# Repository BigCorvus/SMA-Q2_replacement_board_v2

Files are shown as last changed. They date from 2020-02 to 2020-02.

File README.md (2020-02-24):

# SMA-Q2_replacement_board_v2
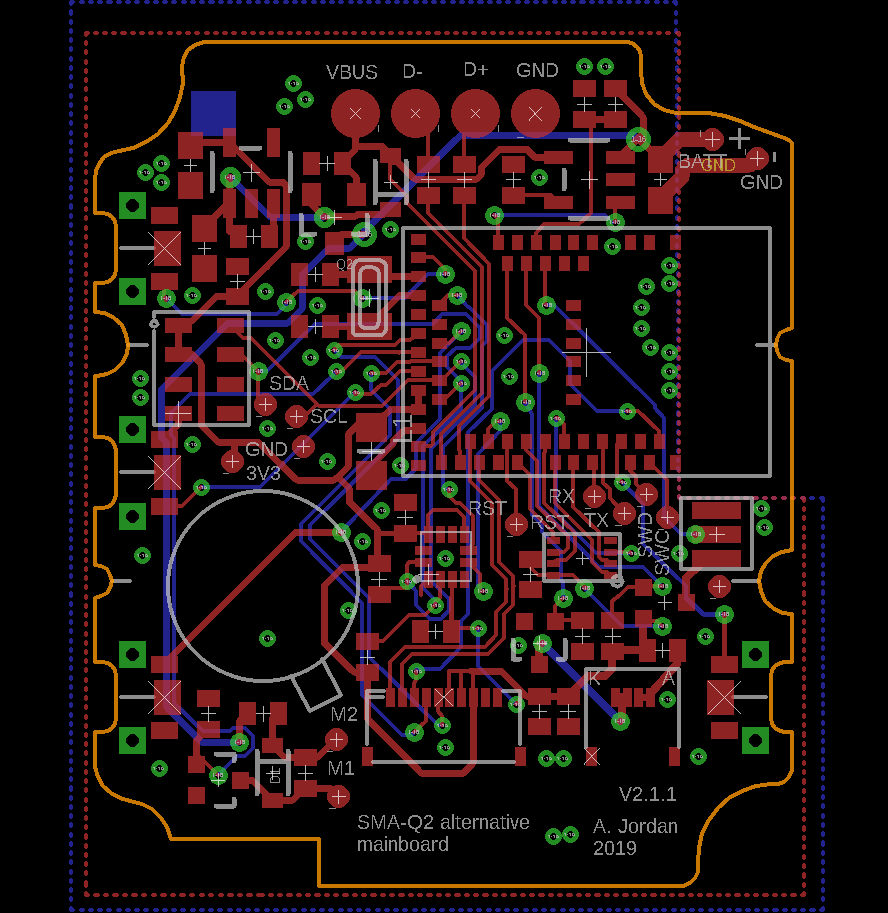
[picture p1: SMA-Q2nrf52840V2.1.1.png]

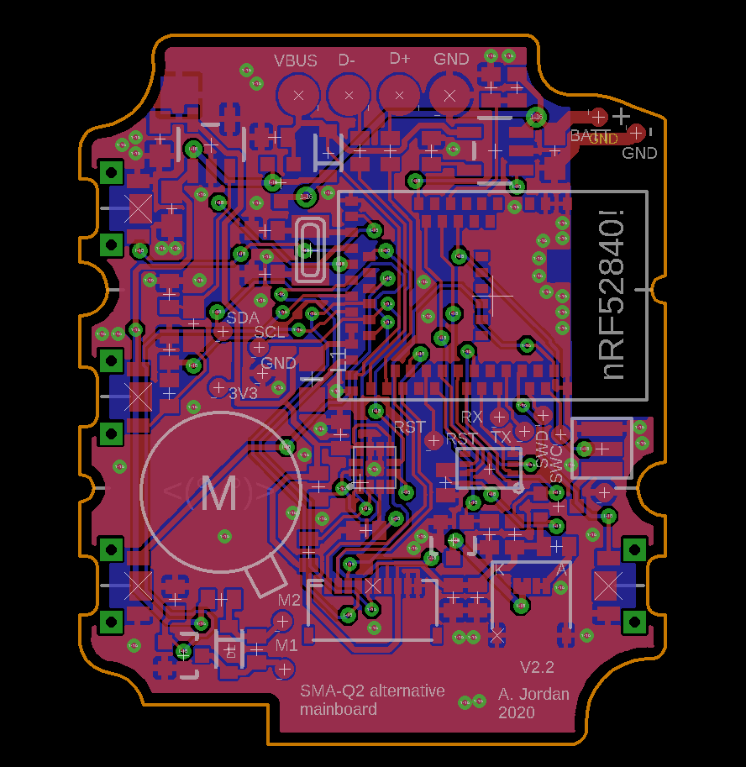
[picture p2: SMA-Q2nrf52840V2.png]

nRF5840-based replacement board for the SMA-Q2 smartwatch. Uses the MDBT50Q-1MV2 (and similar) module. Based on the Adafruit Feather nRF52840. Has to be fabricated on 0,8mm FR4 material. Main changes are: no external RTC, all mosfets in SOT-323 package (at least in v2.2), optional barometer and power latching circuit, everything controlled by the nRF52840.

2 versions have been created: v2.2 without MS5611 barometer, but with a simple power latching circuit. v2.1.1 does not have a power latching circuit, but has a footprint for a MS5611 barometer. Both versions use both interrupts of the accelerometer.  
During testing and everyday use RF performance turned out to be poor. The reason is the ceramic antenna which is shielded by the close proximity of the lipo battery. This problem was quite easy to solve in retrospective. I just desoldered the chip antenna with 2 soldering irons and connected a simple 30AWG wire which I shortened until reception started to get worse. Ended up with about 20mm of wire bent around the top left corner of the device where least interfering metal is located. Quite surprising that the antenna is quite a bit shorter than one would expect for 2.4GHz (lambda/4 = ~31mm). Let me tell you, at 5dbm TX power the wireless range and link reliability is now really good! FCC compliance is now goneski of course.  
This got me motivated to create a 3rd version of the board using the bare chip instead of an integrated module. It makes use of the inbuilt antenna which is also surprisingly short (about 20mm). The feedline was designed to be about 50 ohm (although it probably doesn't have to be, in the original version it's about 65 ohm at 0,7mm trace width and 0.8mm FR4 substrate). This version 2.3 has the barometer, which has proven to be very accurate and useful, the power latching circuit and even a fuel gauge which can measure the supply current (albeit in 1mA steps).  
Another feature that proved to be very useful if you like to wear a dev platform on your wrist is a normally closed reed switch in series with the battery so you can power cycle the device if bricked with a magnet (the charging cable f.e.) or just keep the battey disconnected by attaching a magnet to it if the device is not in use and has to be stored for longer periods of time. The pads on the bottom of the board are there to keep the reed switch in place. The battery therefore connects to the leftmost contact (one arm of the reed switch) and GND. I used the smallest SPDT (3 pins) reed switch I could find. Its glass body is 15mm long. Just trim the unused leg and bend the other two in shape carefully making sure the delicate glass body stays intact.   

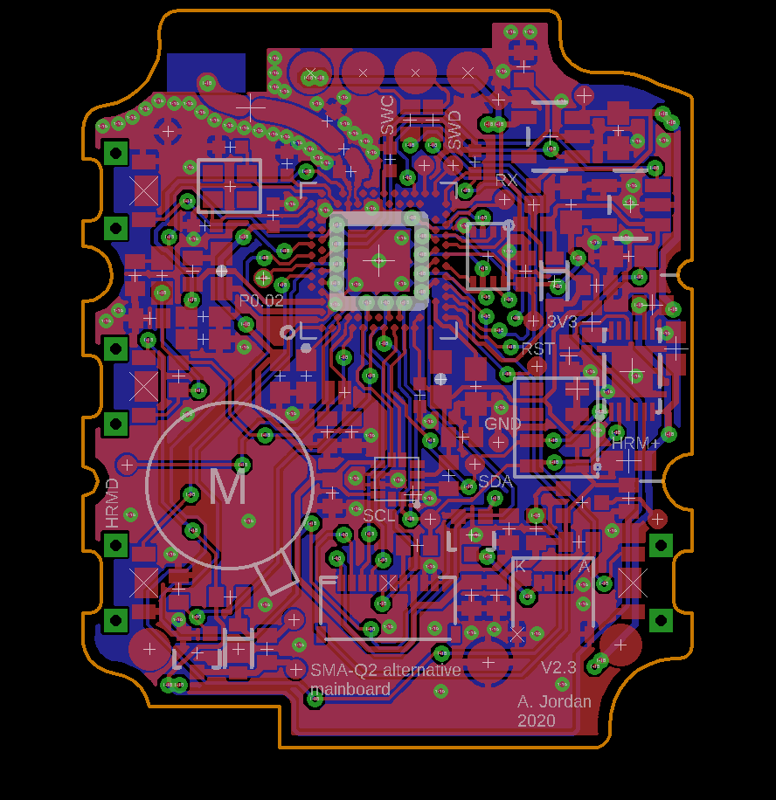
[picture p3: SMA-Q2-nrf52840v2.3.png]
  

Note: 2.3 has not been tested yet. The Feather bootloader should still work, the pinout for the button, I2C, SPI, QSPI and UART is still the same.

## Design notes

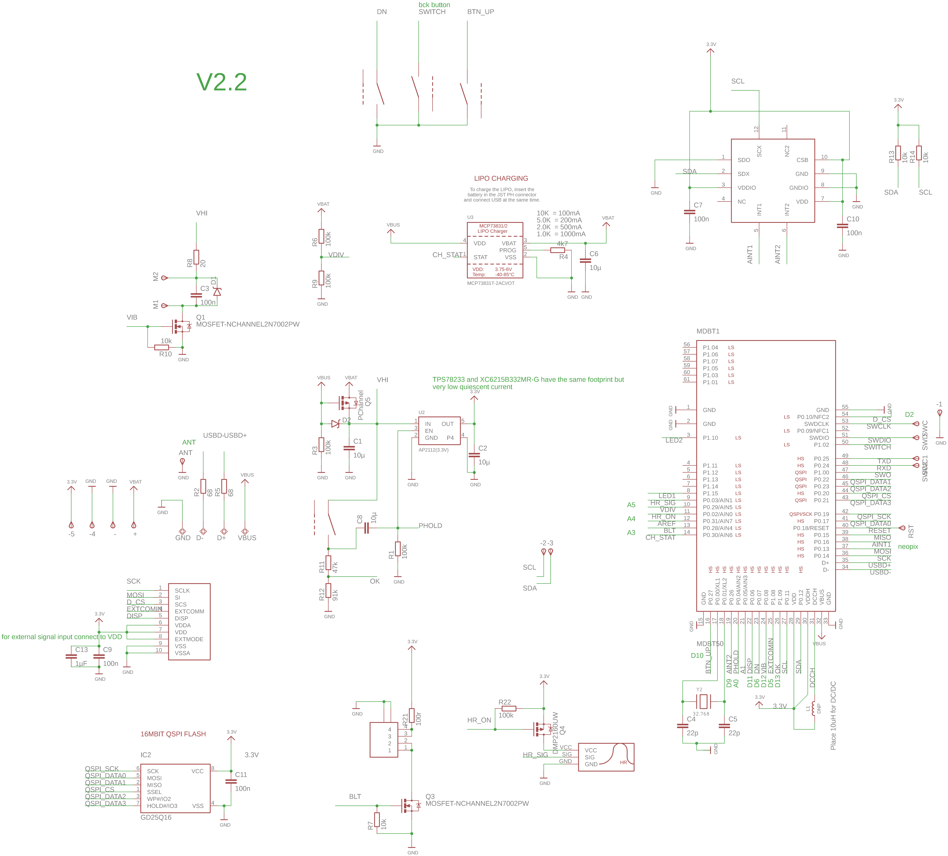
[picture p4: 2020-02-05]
SMA-Q2nrf52840V2sch.png

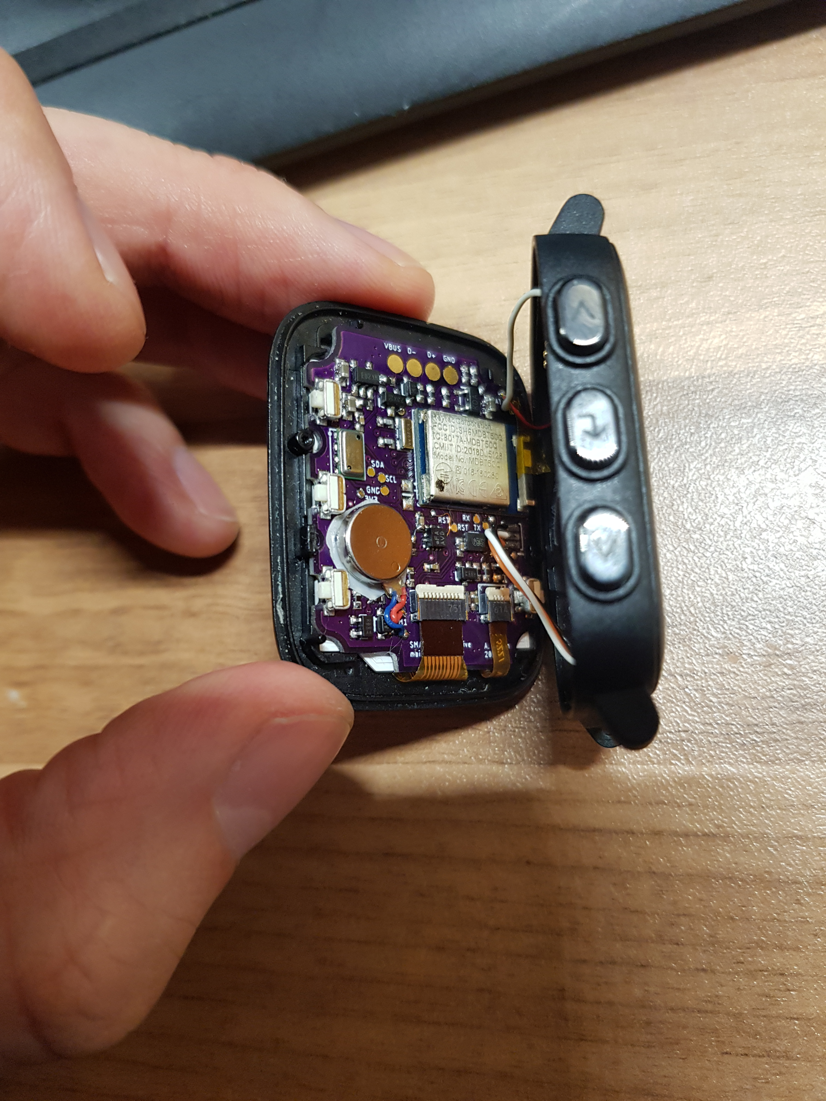
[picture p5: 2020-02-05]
SMA-Q2-replacementBoardv2.jpg

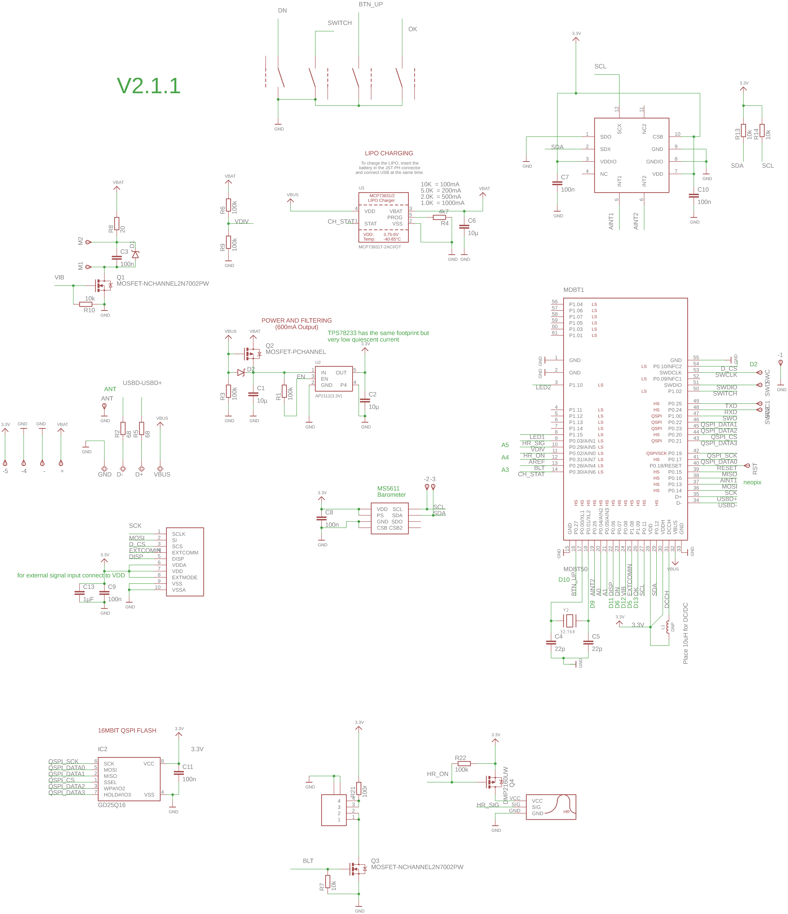
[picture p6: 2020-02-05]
SMA-Q2nrf52840V2.1.1sch.png

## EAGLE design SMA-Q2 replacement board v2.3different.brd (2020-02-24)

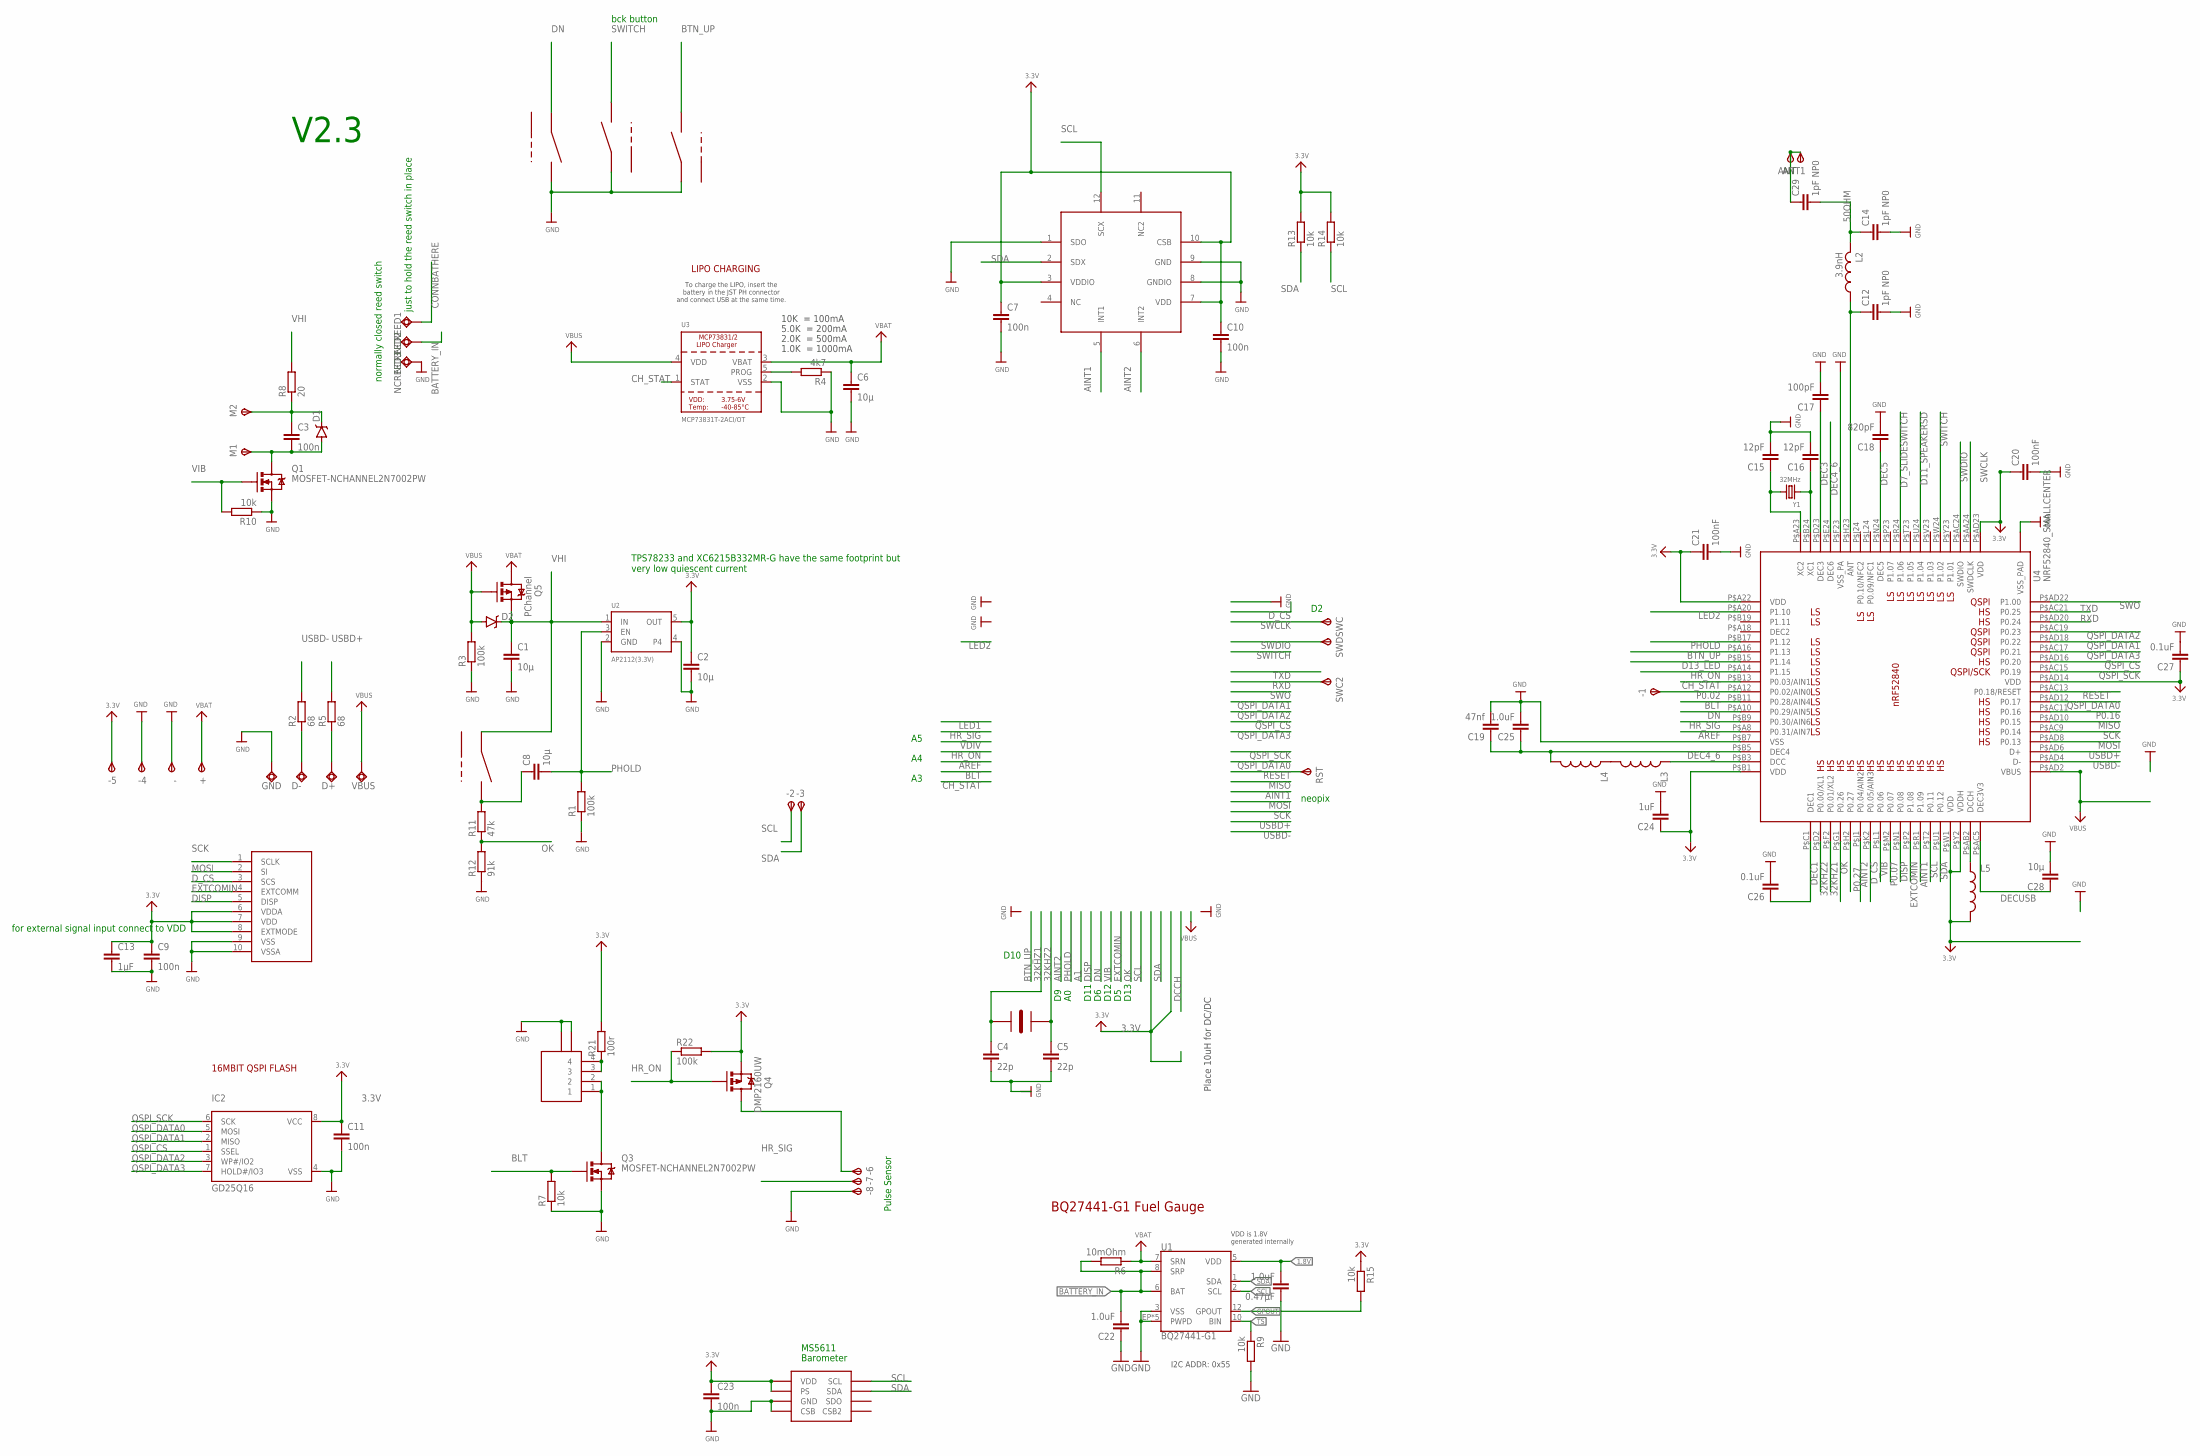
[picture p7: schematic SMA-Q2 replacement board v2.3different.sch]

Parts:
0.47µF: 1.0uF; RESC0603_N
+: TPSTP09R; TP09R
-, -1, -2, -3, -4, -5, -6, -7, -8: TPSTP09R; TP09R
ANT, ANT1: TPSTP19SQ; TP19SQ
C1, C2, C6, C8, C28: 10µ; C0603
C3, C7, C9, C10, C11, C23: 100n; C0402
C4, C5: 22p; C0402
C12, C14, C29: 1pF NP0; RESC0402_N
C13: 1µF; C0402
C15, C16: 12pF; RESC0402_N
C17: 100pF; RESC0402_N
C18: 820pF; RESC0402_N
C19: 47nf; RESC0603_N
C20, C21: 100nF; RESC0402_N
C22, C25: 1.0uF; RESC0603_N
C24: 1uF; RESC0603_N
C26: 0.1uF; RESC0603_N
C27: 0.1uF; RESC0402_N
D1, D2: BAT20J; SOD-323
D+: TPSQTP20R; TP20R
D-: TPSQTP20R; TP20R
DWN, DWN1, DWN2, DWN3: LS12T2
GND: TPSQTP20R; TP20R
IC2: GD25Q16; USON8
L2: 3.9nH; RESC0402_N
L3, L5: INDUCTOR30OHM,1.8A; 0603
L4: INDUCTOR0402; C0402
M1, M2: TPSTP09R; TP09R
NCREED1, NCREED2, NCREED3: TPSQTP20R; TP20R
Q1, Q3: MOSFET-NCHANNEL2N7002PW; SOT323
Q4: DMP2160UW; SOT323
Q5: PChannel; SOT323
R1, R3, R22: 100k; R0402
R2, R5: 68; R0402
R4: 4k7; R0402
R6: 10mOhm; R0402
R7, R9, R10, R13, R14, R15: 10k; R0402
R8: 20; R0402
R11: 47k; R0402
R12: 91k; R0402
R21: 100r; R0402
RST: TPSTP09R; TP09R
SWC, SWC2: TPSTP09R; TP09R
SWD: TPSTP09R; TP09R
U1: BQ27441-G1; PDSO-N12
U2: AP2112(3.3V); SOT23-5
U3: MCP73831T-2ACI/OT; SOT23-5
U4: NRF52840_SMALLCENTER; AQFN50P700X800X85_HS-74N_SMALLCENTER
U$2: SHARP_MEM_DISP; Y5BW
U$6: Y5B-4PIN
U$7: BMA400
U$45: MC5611; MS5611
U$81: ECX-1210
VBUS: TPSQTP20R; TP20R
Y1: 32MHz; CRYSTAL_2.5X2

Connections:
1.8V: 0.47µF.2, U1.5 (VDD)
3.3V: -5.TP, C2.1, C7.1, C9.1, C10.1, C11.1, C13.1, C20.1, C21.1, C23.1, C24.1, C27.1, IC2.8 (VCC), L5.2, Q4.2 (S), R13.2, R14.2, R15.1, R21.2, R22.2, U2.5 (OUT), U4.P$A22 (VDD), U4.P$AD14 (VDD), U4.P$AD23 (VDD), U4.P$B1 (VDD), U4.P$W1 (VDD), U4.P$Y2 (VDDH), U$2.6 (VDDA), U$2.7 (VDD), U$2.8 (EXTMODE), U$7.3 (VDDIO), U$7.7 (VDD), U$7.10 (CSB), U$45.PS, U$45.VDD
32KHZ1: C4.1, U4.P$F2 (P0.01/XL2), U$81.P$1
32KHZ2: C5.1, U4.P$D2 (P0.00/XL1), U$81.P$2
50OHM: C14.1, C29.2, L2.2
AINT1: U4.P$R1 (P1.09), U$7.5 (INT1)
AINT2: U4.P$J1 (P0.04/AIN2), U$7.6 (INT2)
AREF: U4.P$A8 (P0.31/AIN7)
BATTERY_IN: C22.2, NCREED2.TP, R6.2, U1.6 (BAT), U1.8 (SRP)
BLT: Q3.1 (G), R7.2, U4.P$B11 (P0.28/AIN4)
BTN_UP: DWN2.1, U4.P$A16 (P1.13)
CH_STAT: U3.1 (STAT), U4.P$B13 (P0.03/AIN1)
CONNBATHERE: NCREED1.TP
D7_SLIDESWITCH: U4.P$R24 (P1.06)
D11_SPEAKERSD: U4.P$U24 (P1.04)
D13_LED: U4.P$B15 (P1.14)
DEC1: C26.1, U4.P$C1 (DEC1)
DEC3: C17.1, U4.P$D23 (DEC3)
DEC4_6: C19.1, C25.1, L4.2, U4.P$B5 (DEC4), U4.P$E24 (DEC6)
DEC5: C18.1, U4.P$N24 (DEC5)
DECUSB: C28.1, U4.P$AC5 (DEC3V3)
DISP: U4.P$N1 (P0.08), U$2.5 (DISP)
DN: DWN.2, U4.P$A10 (P0.29/AIN5)
D_CS: U4.P$K2 (P0.05/AIN3), U$2.3 (SCS)
EXTCOMIN: U4.P$P2 (P1.08), U$2.4 (EXTCOMM)
GND: 0.47µF.1, -.TP, -4.TP, -8.TP, C1.2, C2.2, C4.2, C5.2, C6.2, C7.2, C9.2, C10.2, C11.2, C12.2, C13.2, C14.2, C15.2, C16.2, C17.2, C18.2, C19.2, C20.2, C21.2, C22.1, C23.2, C24.2, C25.2, C26.2, C27.2, C28.2, DWN.1, DWN1.2, DWN2.2, GND.TP, IC2.4 (VSS), NCREED3.TP, Q1.2 (S), Q3.2 (S), R1.1, R3.1, R4.1, R7.1, R9.2, R10.1, R12.1, U1.3 (VSS), U1.EP (PWPD), U1.EP1 (PWPD), U1.EP2 (PWPD), U1.EP3 (PWPD), U1.EP4 (PWPD), U2.2 (GND), U2.4, U3.2 (VSS), U4.P$B7 (VSS), U4.P$F23 (VSS_PA), U4.THERMPAD (VSS_PAD), U$2.9 (VSS), U$2.10 (VSSA), U$6.H1, U$6.H2, U$7.1 (SDO), U$7.8 (GNDIO), U$7.9 (GND), U$45.CSB, U$45.GND
GPOUT: R15.2, U1.12 (GPOUT)
HR_ON: Q4.1 (G), R22.1, U4.P$A14 (P1.15)
HR_SIG: -7.TP, U4.P$B9 (P0.30/AIN6)
LED2: U4.P$A20 (P1.10)
MISO: U4.P$AD10 (P0.15)
MOSI: U4.P$AD8 (P0.13), U$2.2 (SI)
unnamed: Q3.3 (D), U$6.1, U$6.2
unnamed: C8.1, DWN3.1, R11.2
unnamed: D-.TP, R2.1
unnamed: D+.TP, R5.1
unnamed: C12.1, L2.1, U4.P$H23 (ANT)
unnamed: L3.2, L4.1
unnamed: L3.1, U4.P$B3 (DCC)
unnamed: L5.1, U4.P$AB2 (DCCH)
unnamed: R21.1, U$6.3, U$6.4
unnamed: -6.TP, Q4.3 (D)
unnamed: R4.2, U3.5 (PROG)
unnamed: C3.2, D1.A, M1.TP, Q1.3 (D)
unnamed: C3.1, D1.C, M2.TP, R8.1
unnamed: C15.1, U4.P$A23 (XC2), Y1.3 (2)
unnamed: C16.1, U4.P$B24 (XC1), Y1.1
OK: R11.1, R12.2, U4.P$G1 (P0.26)
P0.02: -1.TP, U4.P$A12 (P0.02/AIN0)
P0.07: U4.P$M2 (P0.07)
P0.16: U4.P$AC11 (P0.16)
P0.27: U4.P$H2 (P0.27)
PHOLD: C8.2, R1.2, U2.3 (EN), U4.P$B17 (P1.12)
QSPI_CS: IC2.1 (SSEL), U4.P$AD16 (P0.20)
QSPI_DATA0: IC2.5 (MOSI), U4.P$AD12 (P0.17)
QSPI_DATA1: IC2.2 (MISO), U4.P$AD18 (P0.22)
QSPI_DATA2: IC2.3 (WP#/IO2), U4.P$AC19 (P0.23)
QSPI_DATA3: IC2.7 (HOLD#/IO3), U4.P$AC17 (P0.21)
QSPI_SCK: IC2.6 (SCK), U4.P$AC15 (P0.19)
RESET: RST.TP, U4.P$AC13 (P0.18/RESET)
RF: ANT.TP, ANT1.TP, C29.1
RXD: SWC2.TP, U4.P$AD20 (P0.24)
SCK: U4.P$AC9 (P0.14), U$2.1 (SCLK)
SCL: -2.TP, R14.1, U1.2 (SCL), U4.P$T2 (P0.11), U$7.12 (SCX), U$45.SCL
SDA: -3.TP, R13.1, U1.1 (SDA), U4.P$U1 (P0.12), U$7.2 (SDX), U$45.SDA
SWCLK: SWC.TP, U4.P$AA24 (SWDCLK)
SWDIO: SWD.TP, U4.P$AC24 (SWDIO)
SWITCH: DWN1.1, U4.P$W24 (P1.02)
SWO: U4.P$AD22 (P1.00)
TS: R9.1, U1.10 (BIN)
TXD: U4.P$AC21 (P0.25)
USBD+: R5.2, U4.P$AD6 (D+)
USBD-: R2.2, U4.P$AD4 (D-)
VBAT: +.TP, C6.1, Q5.3 (D), R6.1, U1.7 (SRN), U3.3 (VBAT)
VBUS: D2.A, Q5.1 (G), R3.2, U3.4 (VDD), U4.P$AD2 (VBUS), VBUS.TP
VHI: C1.1, D2.C, DWN3.2, Q5.2 (S), R8.2, U2.1 (IN)
VIB: Q1.1 (G), R10.2, U4.P$L1 (P0.06)

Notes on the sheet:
Place 10uH for DC/DC
10K = 100mA
5.0K = 200mA
2.0K = 500mA
1.0K = 1000mA
LIPO CHARGING
To charge the LIPO, insert the battery in the JST PH connector and connect USB at the same time.
TPS78233 and XC6215B332MR-G have the same footprint but very low quiescent current
16MBIT QSPI FLASH
for external signal input connect to VDD
D10
D12
neopix
D13
D11
bck button
V2.3
normally closed reed switch
Pulse Sensor
MS5611
Barometer
BQ27441-G1 Fuel Gauge
VDD is 1.8V generated internally
I2C ADDR: 0x55
just to hold the reed switch in place

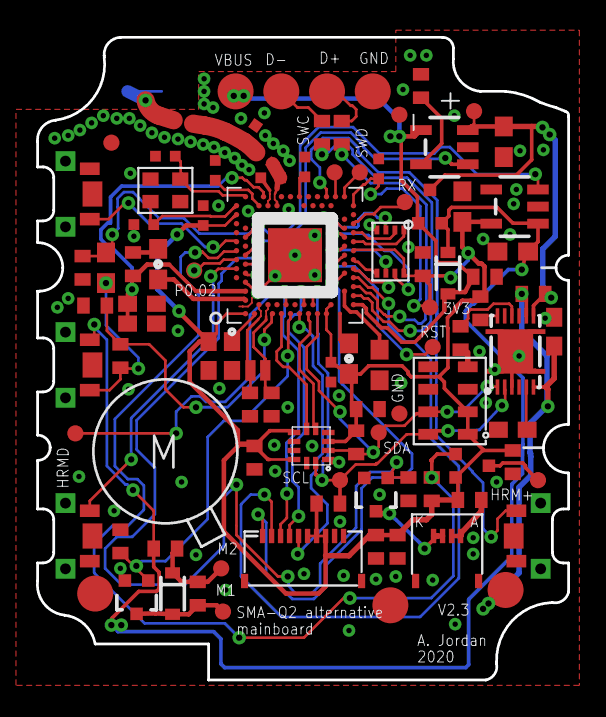
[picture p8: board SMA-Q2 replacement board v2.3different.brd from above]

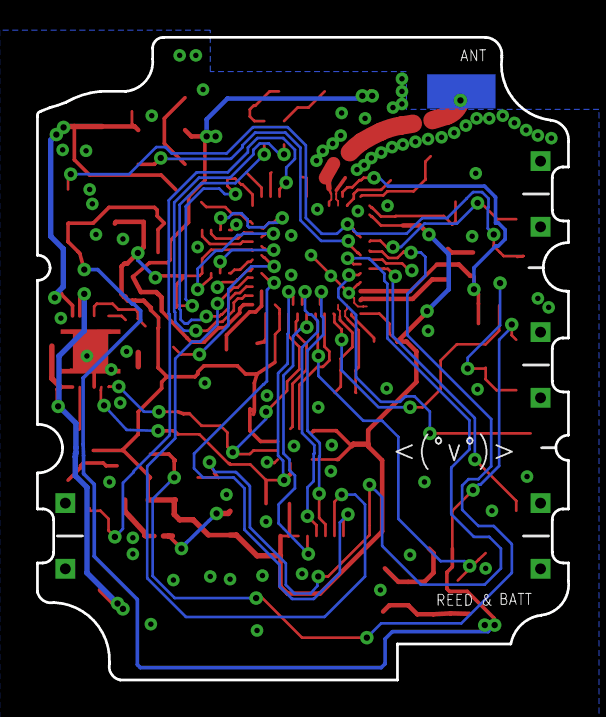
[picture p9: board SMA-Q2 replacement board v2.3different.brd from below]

Board: 2 copper layers, 29.5 x 35.7 mm, 97 parts (2 on the bottom side), 65 nets.

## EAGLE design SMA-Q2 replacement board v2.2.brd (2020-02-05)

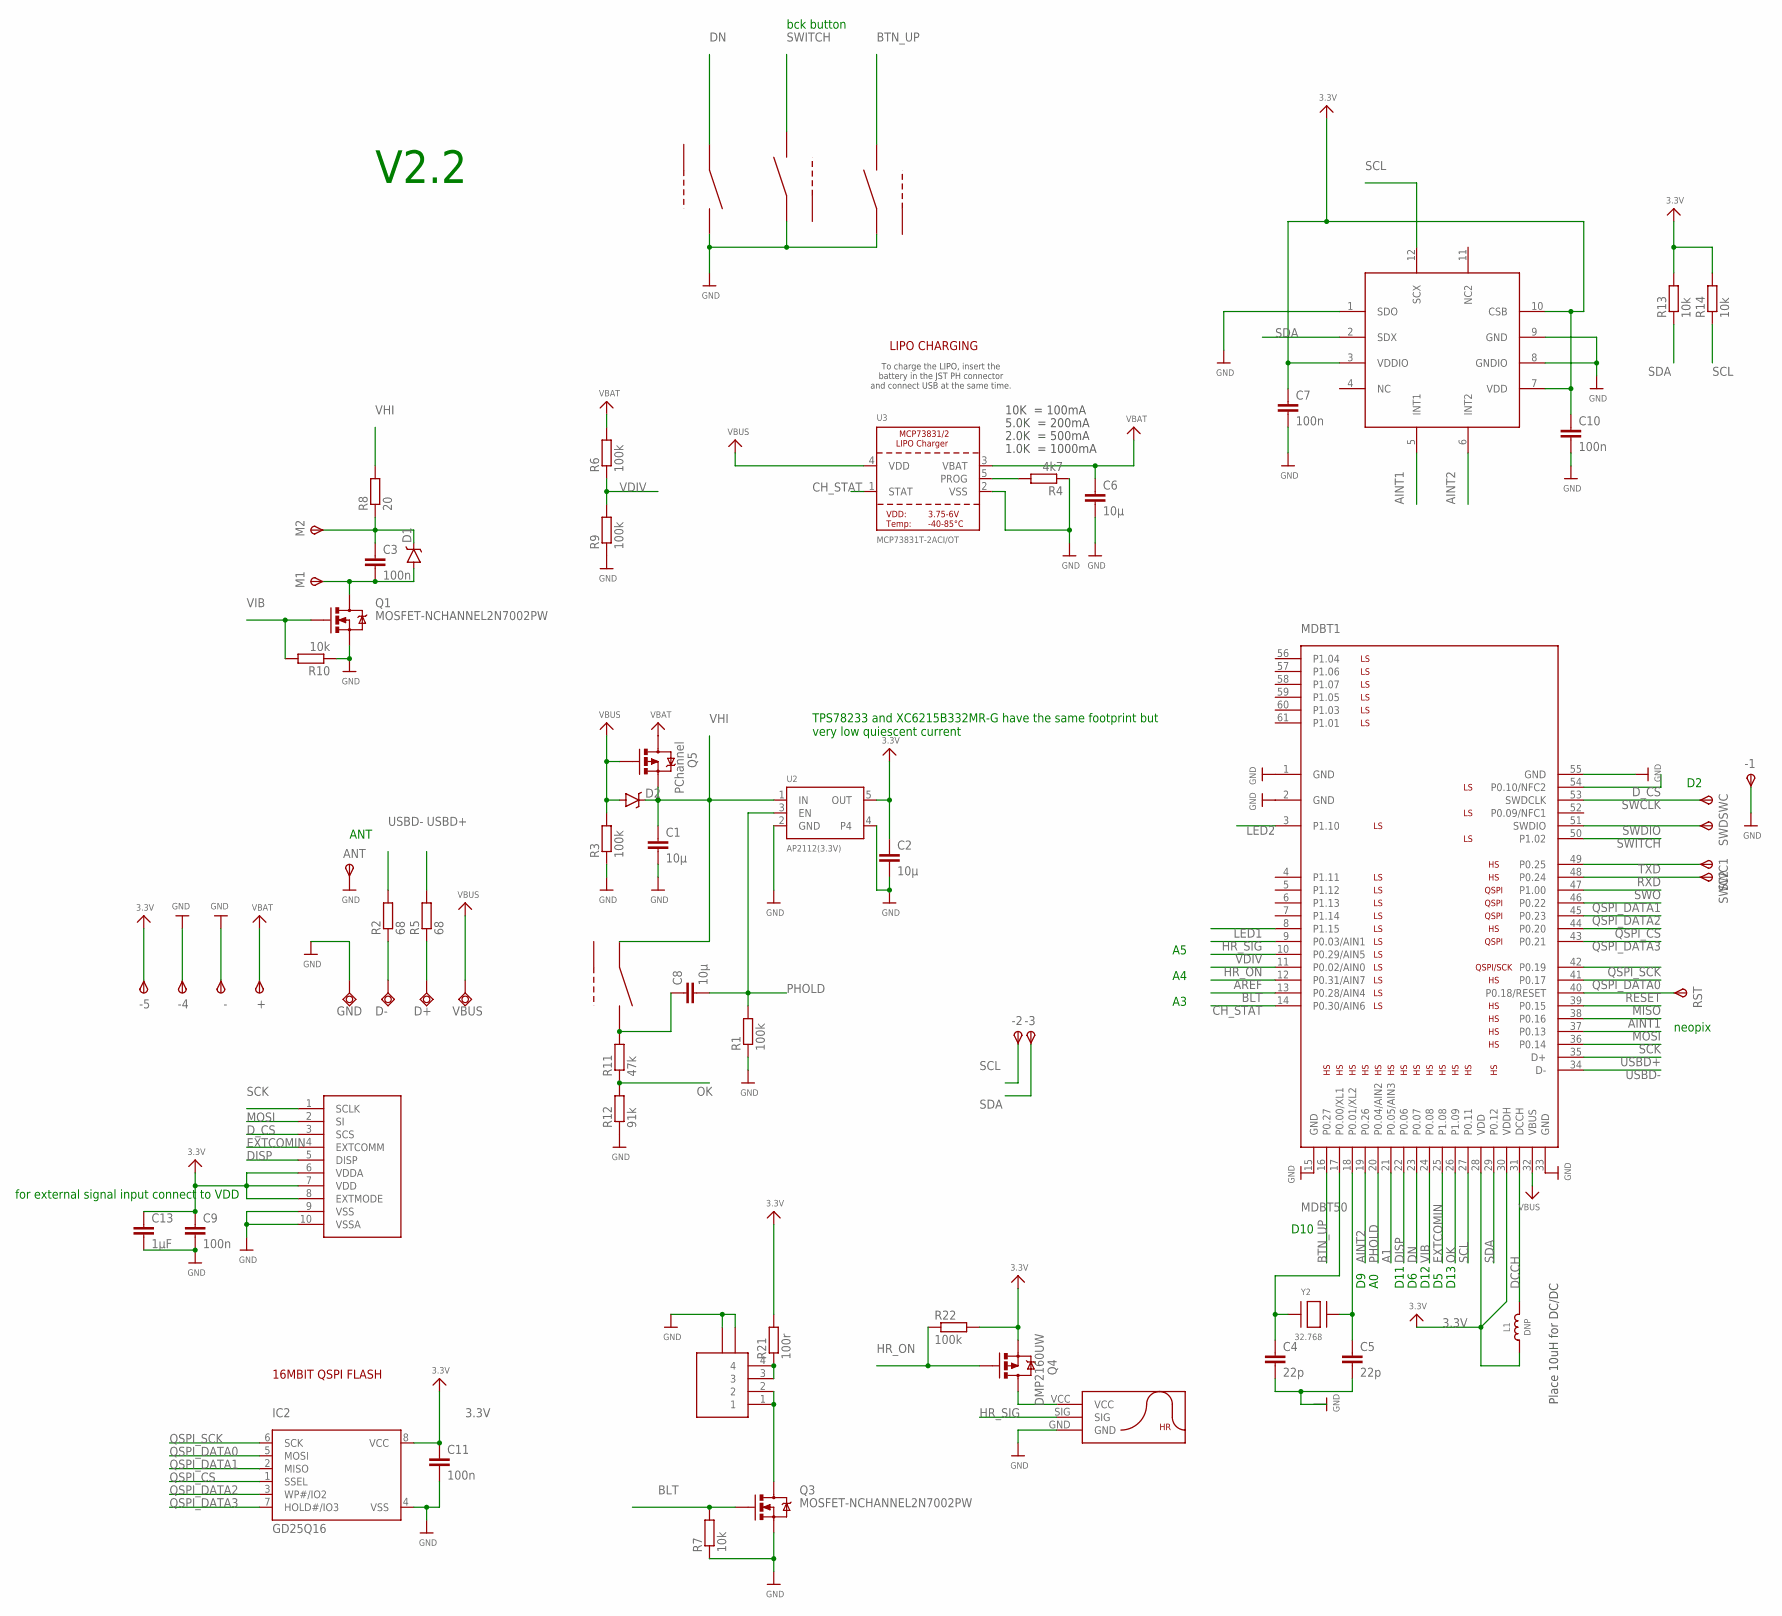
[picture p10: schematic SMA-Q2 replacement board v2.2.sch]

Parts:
+: TPSTP09R; TP09R
-, -1, -2, -3, -4, -5: TPSTP09R; TP09R
ANT: TPSTP19SQ; TP19SQ
C1, C2, C6, C8: 10µ; C0603
C3, C7, C9, C10, C11: 100n; C0402
C4, C5: 22p; C0402
C13: 1µF; C0402
D1, D2: BAT20J; SOD-323
D+: TPSQTP20R; TP20R
D-: TPSQTP20R; TP20R
DWN, DWN1, DWN2, DWN3: LS12T2
GND: TPSQTP20R; TP20R
IC2: GD25Q16; USON8
L1: DNP; _0805MP
M1, M2: TPSTP09R; TP09R
MDBT1: MDBT50
Q1, Q3: MOSFET-NCHANNEL2N7002PW; SOT323
Q4: DMP2160UW; SOT323
Q5: PChannel; SOT323
R1, R3, R6, R9, R22: 100k; R0402
R2, R5: 68; R0402
R4: 4k7; R0402
R7, R10, R13, R14: 10k; R0402
R8: 20; R0402
R11: 47k; R0402
R12: 91k; R0402
R21: 100r; R0402
RST: TPSTP09R; TP09R
SWC, SWC1, SWC2: TPSTP09R; TP09R
SWD: TPSTP09R; TP09R
U2: AP2112(3.3V); SOT23-5
U3: MCP73831T-2ACI/OT; SOT23-5
U$2: SHARP_MEM_DISP; Y5BW
U$6: Y5B-4PIN
U$7: BMA400
U$45: HR_PADS
VBUS: TPSQTP20R; TP20R
Y2: 32.768; XTAL3215

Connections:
3.3V: -5.TP, C2.1, C7.1, C9.1, C10.1, C11.1, C13.1, IC2.8 (VCC), L1.1, MDBT1.28 (VDD), MDBT1.30 (VDDH), Q4.2 (S), R13.2, R14.2, R21.2, R22.2, U2.5 (OUT), U$2.6 (VDDA), U$2.7 (VDD), U$2.8 (EXTMODE), U$7.3 (VDDIO), U$7.7 (VDD), U$7.10 (CSB)
A1: MDBT1.21 (P0.05/AIN3)
AINT1: MDBT1.38 (P0.16), U$7.5 (INT1)
AINT2: MDBT1.19 (P0.26), U$7.6 (INT2)
AREF: MDBT1.12 (P0.31/AIN7)
BLT: MDBT1.13 (P0.28/AIN4), Q3.1 (G), R7.2
BTN_UP: DWN2.1, MDBT1.16 (P0.27)
CH_STAT: MDBT1.14 (P0.30/AIN6), U3.1 (STAT)
DCCH: L1.2, MDBT1.31 (DCCH)
DISP: MDBT1.22 (P0.06), U$2.5 (DISP)
DN: DWN.2, MDBT1.23 (P0.07)
D_CS: MDBT1.54 (P0.10/NFC2), U$2.3 (SCS)
EXTCOMIN: MDBT1.25 (P1.08), U$2.4 (EXTCOMM)
GND: -.TP, -1.TP, -4.TP, ANT.TP, C1.2, C2.2, C4.2, C5.2, C6.2, C7.2, C9.2, C10.2, C11.2, C13.2, DWN.1, DWN1.2, DWN2.2, GND.TP, IC2.4 (VSS), MDBT1.1 (GND), MDBT1.2 (GND), MDBT1.15 (GND), MDBT1.33 (GND), MDBT1.55 (GND), Q1.2 (S), Q3.2 (S), R1.1, R3.1, R4.1, R7.1, R9.1, R10.1, R12.1, U2.2 (GND), U2.4, U3.2 (VSS), U$2.9 (VSS), U$2.10 (VSSA), U$6.H1, U$6.H2, U$7.1 (SDO), U$7.8 (GNDIO), U$7.9 (GND), U$45.GND
HR_ON: MDBT1.11 (P0.02/AIN0), Q4.1 (G), R22.1
HR_SIG: MDBT1.9 (P0.03/AIN1), U$45.SIG
LED1: MDBT1.8 (P1.15)
LED2: MDBT1.3 (P1.10)
MISO: MDBT1.39 (P0.15)
MOSI: MDBT1.37 (P0.13), U$2.2 (SI)
unnamed: Q3.3 (D), U$6.1, U$6.2
unnamed: C8.1, DWN3.1, R11.2
unnamed: D-.TP, R2.1
unnamed: D+.TP, R5.1
unnamed: C4.1, MDBT1.17 (P0.00/XL1), Y2.P$1
unnamed: C5.1, MDBT1.18 (P0.01/XL2), Y2.P$2
unnamed: R21.1, U$6.3, U$6.4
unnamed: R4.2, U3.5 (PROG)
unnamed: C3.2, D1.A, M1.TP, Q1.3 (D)
unnamed: C3.1, D1.C, M2.TP, R8.1
unnamed: Q4.3 (D), U$45.VCC
OK: MDBT1.26 (P1.09), R11.1, R12.2
PHOLD: C8.2, MDBT1.20 (P0.04/AIN2), R1.2, U2.3 (EN)
QSPI_CS: IC2.1 (SSEL), MDBT1.44 (P0.20)
QSPI_DATA0: IC2.5 (MOSI), MDBT1.41 (P0.17)
QSPI_DATA1: IC2.2 (MISO), MDBT1.46 (P0.22)
QSPI_DATA2: IC2.3 (WP#/IO2), MDBT1.45 (P0.23)
QSPI_DATA3: IC2.7 (HOLD#/IO3), MDBT1.43 (P0.21)
QSPI_SCK: IC2.6 (SCK), MDBT1.42 (P0.19)
RESET: MDBT1.40 (P0.18/RESET), RST.TP
RXD: MDBT1.48 (P0.24), SWC2.TP
SCK: MDBT1.36 (P0.14), U$2.1 (SCLK)
SCL: -2.TP, MDBT1.27 (P0.11), R14.1, U$7.12 (SCX)
SDA: -3.TP, MDBT1.29 (P0.12), R13.1, U$7.2 (SDX)
SWCLK: MDBT1.53 (SWDCLK), SWC.TP
SWDIO: MDBT1.51 (SWDIO), SWD.TP
SWITCH: DWN1.1, MDBT1.50 (P1.02)
SWO: MDBT1.47 (P1.00)
TXD: MDBT1.49 (P0.25), SWC1.TP
USBD+: MDBT1.35 (D+), R5.2
USBD-: MDBT1.34 (D-), R2.2
VBAT: +.TP, C6.1, Q5.3 (D), R6.2, U3.3 (VBAT)
VBUS: D2.A, MDBT1.32 (VBUS), Q5.1 (G), R3.2, U3.4 (VDD), VBUS.TP
VDIV: MDBT1.10 (P0.29/AIN5), R6.1, R9.2
VHI: C1.1, D2.C, DWN3.2, Q5.2 (S), R8.2, U2.1 (IN)
VIB: MDBT1.24 (P0.08), Q1.1 (G), R10.2

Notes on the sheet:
Place 10uH for DC/DC
10K = 100mA
5.0K = 200mA
2.0K = 500mA
1.0K = 1000mA
LIPO CHARGING
To charge the LIPO, insert the battery in the JST PH connector and connect USB at the same time.
ANT
TPS78233 and XC6215B332MR-G have the same footprint but very low quiescent current
16MBIT QSPI FLASH
for external signal input connect to VDD
D10
D12
neopix
D13
D11
bck button
V2.2

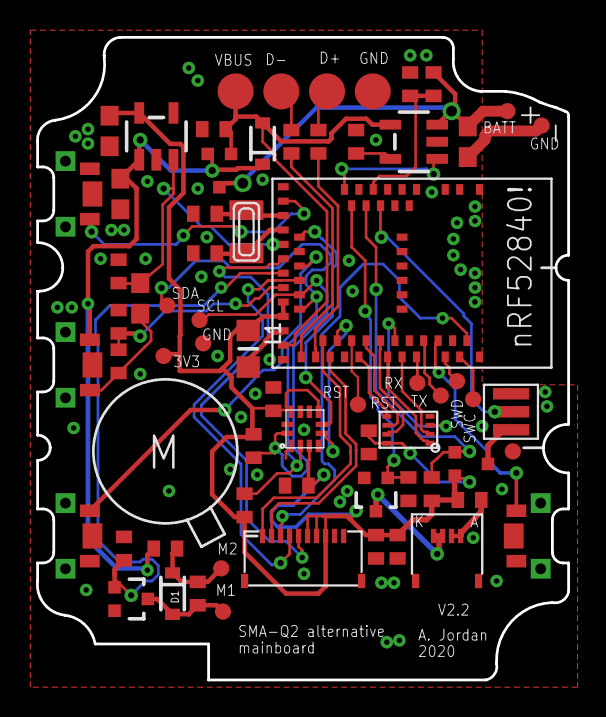
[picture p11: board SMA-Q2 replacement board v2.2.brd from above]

Board: 2 copper layers, 29.5 x 35.7 mm, 67 parts (1 on the bottom side), 50 nets.

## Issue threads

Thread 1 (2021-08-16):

Questions

rroels, 2021-08-16:
Hi!

This is not really an issue, but more like some questions.

I thought this replacement board for the SMA-Q2 was a really cool idea. I like the Q2 hardware more than the SMA-Q3, so I'm considering doing something similar.

- In the first version you had an external RTC to trigger the memory LCD extcomin, to prevent burn-in. In the second version this got removed. May I ask what the reason was? I thought that was a good idea, so I'm guessing there was a down-side to this approach?

- What is the power latching circuit for? Is this to turn off specific peripherals by completely detaching them from the circuit? Or is this a kind of hardware reset for the whole watch? I'm a noob when it comes to electronics, so some clarification for dummies like me would be much appreciated.

Thanks!

BigCorvus, 2021-08-17:
Hi,
I wanted to reduce complexity in the second version and that's why I abandoned the RTC domination as I figured out that I was satisfied with the power comsumption of the nRF52840.
Originally I feared a high power consumption of the system and therefore initially implemented a way of periodically turning it on and off by the RTC, but programming the watch with this power latching in place turned out to be annoyingly complicated. The v2 is much more fun to experiment with and even if you use the Adafruit nrf52 Arduino core, the power consumption is around ~2mA with display on and the MCU running.
Good luck!

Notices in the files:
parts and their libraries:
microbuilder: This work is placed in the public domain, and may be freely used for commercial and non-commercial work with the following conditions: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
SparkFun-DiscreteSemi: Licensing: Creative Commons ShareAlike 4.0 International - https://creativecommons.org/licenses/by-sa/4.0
